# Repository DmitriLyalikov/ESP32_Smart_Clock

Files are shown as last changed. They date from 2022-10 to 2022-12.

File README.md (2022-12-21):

# ESP32 Smart Clock 
This is my Embedded Systems Design Semester Project. I am using the ESP32 platform to make a LCD digital clock that displays local time synchronised from an NTP server and local/current weather forecasts from a JSON weather API endpoint over HTTP. 

This repository contains all the subcomponents, design files, and source code for this system. It is designed to work out 'of the box'. 

Demonstration Video: https://www.youtube.com/watch?v=tQ15JdgLJVc

worker - Copy
### Demonstration Hardware 
* ESP32-DevKitC-V4 (ESP32 Based evaluation board)
* LCD 2004            ( 4x16 LCD)
* PCF8574 I2C Adaptor ( LCD I2C Controller)
* 3D Printed PLA Enclosure ( Front, Rear, and Side Supports)

#### Enclosure 
The 3D printed .stl design files are included in the /enclosure subdirectory. These three components are printed using the Creality CR-10S4 3D printer. Total printing time is about 6.5 hours with the following settings. The output file was generated using the Ultimaker Cura software.
#### Input File


* Resolution: .28
* Infill: 5%
* Material: PLA 

#### Output:
Output

#### Assembled:
Front_View

### Live Weather 
Weather information like Precipitation, Clouds, Pressure, Temperature, Wind are accessed for the desired City or GeoLocation via the  https://openweathermap.org/current HTTP server. This has an API which processes HTTP requests and returns a JSON response including the weather data. 

#### API interaction
An API key is required to acceess the API. It is also appended into the query string of HTTP requests. To get a new API key for a new device, register at https://openweathermap.org/api.  



To verify this key works correctly, wait 10 minutes since activation and request this URL in a browser:
```console
http://api.openweathermap.org/data/2.5/weather?q=Lisbon,pt&APPID={yourAPIkey}
```

The base endpoint is: 
```console 
api.openweathermap.org/data/2.5/weather
```
A query parameter is passed that includes the City, Country code following 
ISO 31666 Country codes (https://en.wikipedia.org/wiki/List_of_ISO_3166_country_codes. 
In our case for New York City, USA the q-parameter is: 
```console
q=NY,US
```

With both an API key, and city, a complete query will appear as: 
```console
http://api.openweathermap.org/data/2.5/weather?q={City},pt&APPID={yourAPIkey}
```

### NTP Synchronization
In order to synchronize time accurately, the ESP-IDF LwIP SNTP module is used. https://github.com/espressif/esp-idf/tree/master/examples/protocols/sntp
This provides time synchronizations over WiFi upon initialization. Upon reset, WiFi will be initialized and an SNTP server connection will be started with the ESP32 acting as a client. 

#### Set Timezone
To set local timezone, use setenv and tzset POSIX functions. First, call setenv to set TZ environment variable to the correct value depending on device location. Format of the time string is described in libc documentation. Next, call tzset to update C library runtime data for the new time zone. Once these steps are done, localtime function will return correct local time, taking time zone offset and daylight saving time into account.

#### TimeKeeping
Once time is synchronized, ESP32 will perform timekeeping using built-in timers.

* RTC clock is used to maintain accurate time when chip is in deep sleep mode

* High-resolution timer is used to provide time at microsecond accuracy when ESP32 is running.

### Using this application
This application is created in the esp-idf framework. The toolchain, compiler, drivers, all can be installed locally here: https://docs.espressif.com/projects/esp-idf/en/latest/esp32/get-started/

This application was developed on a Windows system, and the windows installer: https://docs.espressif.com/projects/esp-idf/en/latest/esp32/get-started/windows-setup.html can be found here that automates the setup process. 
Upon installation and following these steps, a ESP_IDF 4.x CMD utility will be installed, which is a development environment for esp-idf based projects. Open this. I used version 4.4, but a newer version may be available upon completion of this project.
#### Configure ESP-IDF
```console
install
export.bat
```
#### Configure and build this project
```console
cd projects
git clone https://github.com/DmitriLyalikov/ESP32_Smart_Clock.git
cd ESP32_Smart_Clock
idf.py fullclean
idf.py set-target ESP32
idf.py build
```

#### Flashing and Running
With the ESP32 connected via USB, connected to 'COMx'
```
idf.py flash monitor 'COMx'
```
This will flash the application onto the system, and restart, it will then provide serial access to the application. This is not needed to use the clock, but is useful to ensure it flashed successfully. 

#### Configure Application settings
Some configurations may need to be made when using this application. Wifi SSID, Password, and authentication mode must be set before using this app, or the defaults will be used. Generally each component will have a configuration manager that is defined in components/component/Kconfig.Projbuild . Instead of editing hard-coded values in each component source file, a menuconfig utility is provided that can edit these values via command utility:
```console
idf.py menuconfig
```
* Menuconfig Main menu


* Wifi Configuration 


### General Project Structure
```
├── CMakeLists.txt
├── components                 Developer created component sources
    |──ble-config              Bluetooth/BLE configuration functions for controlling system settings at runtime
    |──htttp                   Creates/Processes HTTP requests
    ├──i2c-lcd1602             Functions and resources to interact with an LCD display. 3rd party library (will not be tested)
    |──jsmn                    Third Party lightweight JSON parser: https://github.com/zserge/jsmn
    ├──esp32-smbus             smbus/i2c driver that lcd requires. 3rd party library (will not be tested)
    ├──net_ctlr                event handler, wifi config, web request functions for networking functions (May be split up into further subcomponents)
    ├──ntp_sync                NTP-RTC functions for time synchronization
    ├──weather_sync            Request/Get/Parse/Send Weather Requests over HTTP with thread safe queue implementation between tasks/timers
├── main
│   ├── CMakeLists.txt
│   ├── component.mk    
│   |── Kconfig.Projbuild
│   └── Weather_Clock.c        Entry point to main application. 
├── test                       Unity based subproject for entering test application
│   ├── CMakeLists.txt   
│   ├── component.mk    
│   |── main                     
│   └── build
├── enclosure                  Design (.stl) files for 3D printed system enclosure
├── schematic                  .pdf files of circuit schematic for prototype design. TODO: Create custom PCB 
├── Makefile                   Makefile used by legacy GNU Make
└── README.md                  This is the file you are currently reading
```

### Component Structure
Each component contains an include directory where the component_name.h is kept, and a test subdirectory where unit tests are defined for this component.
As discussed before, each component also has a KConfig.Projbuild that is used to configure some settings like pin assignments, clock rates, etc. 
```
├── CMakeLists.txt
├── component.mk
├── component_name.c
├── KConfig.Projbuild
├── include              
    ├──component_name.h                   
├── test
│   ├── CMakeLists.txt
│   ├── component.mk    
│   └── test_component_name.c  
```
This structure allows a clear dependency tree for our entry point at Weather_Clock.c in /main. All functions, definitions and types are brought into the main namespace by including the header file in our application. It is important to note that this inclusion also brings the components dependencies into scope as well. For example, i2c-lcd1602 component depends on the esp32-smbus component for its i2c driver, and by using #include "i2c-lcd1602.h" in Weather_Clock.c,
esp32-smbus has also been included, by association. 
### Testing
To verify that the system components work as designed, a /test directory is created that compiles a test binary based on the Unity framework for unit testing. Each component also has a /test subdirectory, ie. /components/net_ctlr/test that has defined Test cases with the unity macro: TEST_CASE("Test_name", "[args]")

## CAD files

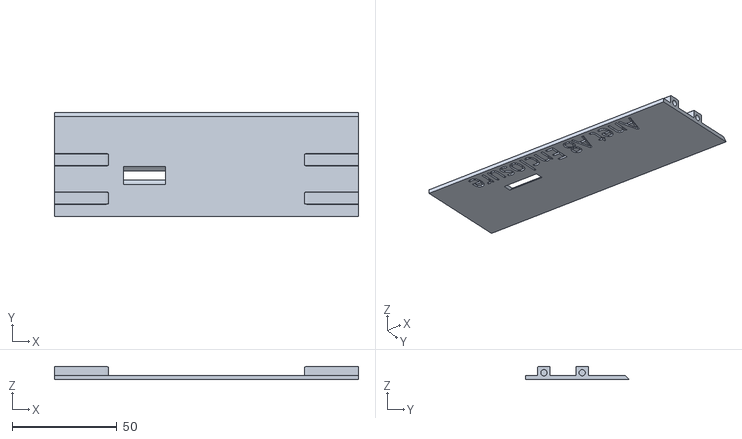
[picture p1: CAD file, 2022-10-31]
enclosure/lcd_support_rear_v3.stl
145.0 x 49.5 x 6.25

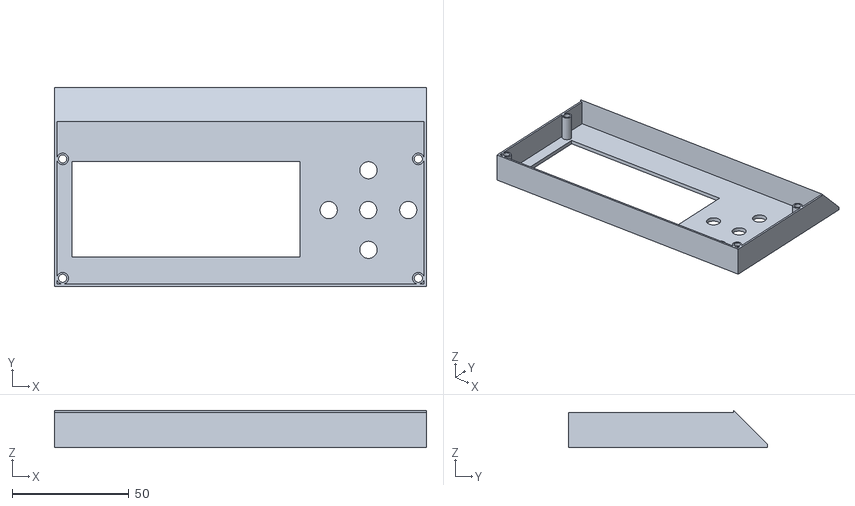
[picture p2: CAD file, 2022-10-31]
enclosure/lcd_front_v3.stl
159.0 x 85.0 x 16.0

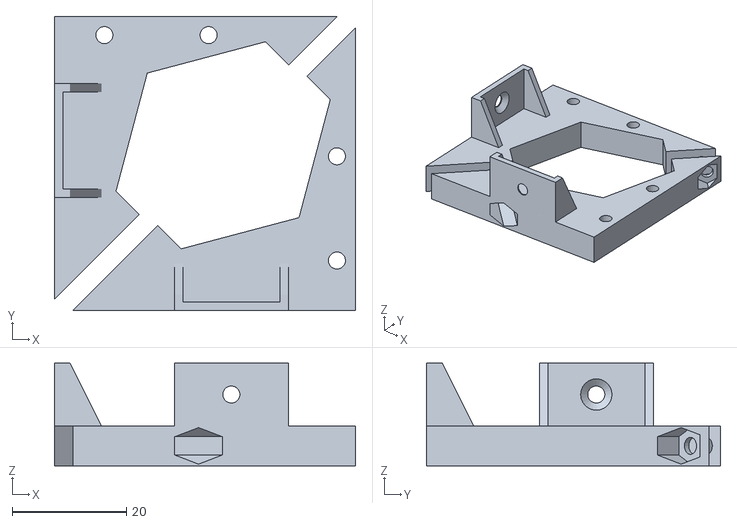
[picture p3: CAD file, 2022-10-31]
enclosure/lcd_supports_45_v3.stl
52.8 x 51.5 x 18.0

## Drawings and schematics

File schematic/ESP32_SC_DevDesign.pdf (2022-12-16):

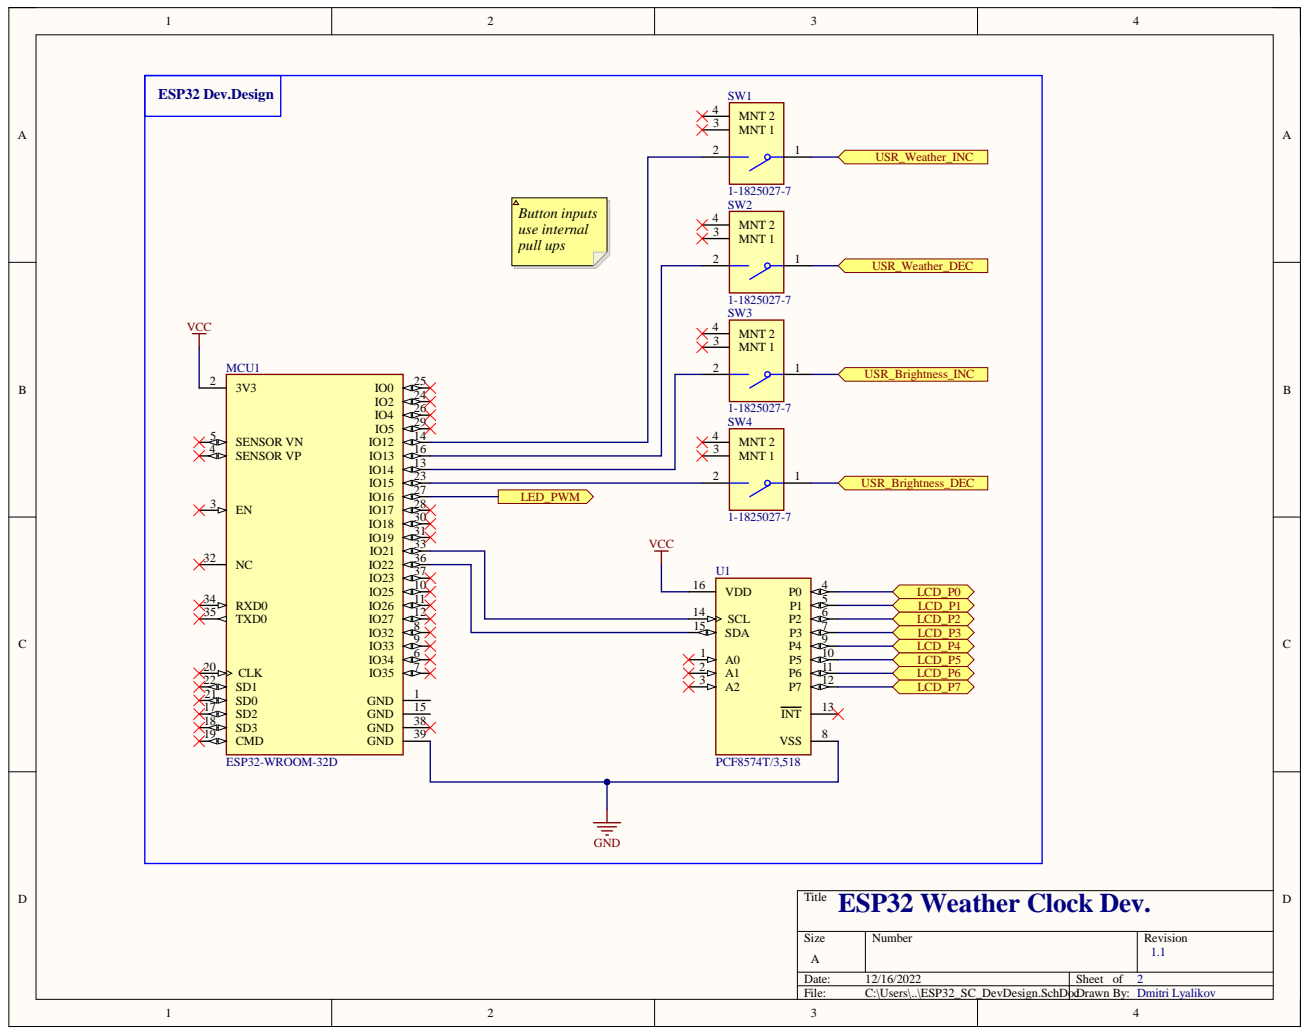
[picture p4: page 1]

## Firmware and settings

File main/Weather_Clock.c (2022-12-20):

/**
 * @file Weather_Clock.c
 * @author Dmitri Lyalikov (Dlyalikov01@manhattan.edu)
 * @brief  Entry Point to ESP32 Weather Clock Application for EECE 321 Final Project 
 * @version 1.2
 * @date 2022-11-14
 */

#include <stdio.h>
#include <string.h>
#include <time.h> 

#include <sys/time.h>
#include "esp_log.h"
#include "esp_err.h"
#include "esp_system.h"
#include "freertos/FreeRTOS.h"
#include "freertos/task.h"
#include "freertos/timers.h"
#include "nvs_flash.h"
#include "perfmon.h"
#include "sdkconfig.h"
#include "driver/i2c.h"

#include "ble_config.h"
#include "smbus.h"
#include "i2c-lcd1602.h"
#include "net_ctlr.h"
#include "ntp_sync.h"
#include "weather.h"
#include "button_irq.h"

#define TIMEZONE              CONFIG_TIMEZONE
#define CITY                  CONFIG_CITY
#define NTP_RESYNC_PERIOD     CONFIG_NTP_RESYNC_PERIOD
#define WEATHER_RESYNC_PERIOD CONFIG_NTP_RESYNC_PERIOD

static const char* TAG = "Weather Clock";

// FreeRTOS Task Shared Resources
static TimerHandle_t xNTP_SYNC_TIMER;
static TimerHandle_t xWEATHER_SYNC_TIMER;
static QueueHandle_t xWeatherSyncQueue;

/**
 * @brief Initialise I2C Master Bus before display communication
 */
static void i2c_master_init(void)
{
    int i2c_master_port = I2C_MASTER_NUM;
    i2c_config_t conf;
    memset(&conf, 0, sizeof(i2c_config_t));
    conf.mode = I2C_MODE_MASTER;
    conf.sda_io_num = I2C_MASTER_SDA_IO;
    conf.sda_pullup_en = GPIO_PULLUP_DISABLE;  // GY-2561 provides 10kΩ pullups
    conf.scl_io_num = I2C_MASTER_SCL_IO;
    conf.scl_pullup_en = GPIO_PULLUP_DISABLE;  // GY-2561 provides 10kΩ pullups
    conf.master.clk_speed = I2C_MASTER_FREQ_HZ;
    i2c_param_config(i2c_master_port, &conf);
    i2c_driver_install(i2c_master_port, conf.mode,
                       I2C_MASTER_RX_BUF_LEN,
                       I2C_MASTER_TX_BUF_LEN, 0);
}

/**
 * @brief Display Task 
 * Configure I2C, SMbus, and LCD device
 * Set time zone, get weather data
 * Updates time every 500 ms, and writes to Display
 */
static void vdisplay_task(void *pvParameter) {
    i2c_master_init();
    i2c_port_t i2c_num = I2C_MASTER_NUM;
    uint8_t address = LCD1602_I2C_ADDRESS;

    // Set up the SMBus
    smbus_info_t * smbus_info = smbus_malloc();
    ESP_ERROR_CHECK(smbus_init(smbus_info, i2c_num, address));
    ESP_ERROR_CHECK(smbus_set_timeout(smbus_info, 1000 / portTICK_RATE_MS));

    // Set up the LCD1602 device with backlight off
    i2c_lcd1602_info_t * lcd_info = i2c_lcd1602_malloc();
    ESP_ERROR_CHECK(i2c_lcd1602_init(lcd_info, smbus_info, true,
                    LCD_NUM_ROWS, LCD_NUM_COLUMNS, LCD_NUM_VISIBLE_COLUMNS));

    ESP_ERROR_CHECK(i2c_lcd1602_reset(lcd_info));

    i2c_lcd1602_write_string(lcd_info, "    Hello Dmitri");
    i2c_lcd1602_move_cursor(lcd_info, 0, 1);
    i2c_lcd1602_write_string(lcd_info, CONFIG_CITY);
     
    weather_data weather_now;
    uint32_t ulWeatherReady;
    vReadQueue(&weather_now, xWeatherSyncQueue);
    char float_read[50];
    time_t now;
    char strftime_buf[64];
    struct tm timeinfo;
    // Set timezone to CONFIG_TIMEZONE
    time(&now);
    setenv("TZ", TIMEZONE, 1);
    tzset();
    i2c_lcd1602_move_cursor(lcd_info, 0, 1);
    i2c_lcd1602_write_string(lcd_info, CONFIG_CITY);
    i2c_lcd1602_move_cursor(lcd_info, sizeof(CONFIG_CITY), 1);
    i2c_lcd1602_write_string(lcd_info, weather_now.description);
    i2c_lcd1602_move_cursor(lcd_info, 0, 3);
    i2c_lcd1602_write_string(lcd_info, "Temp(C):");
    i2c_lcd1602_move_cursor(lcd_info, 8, 3);
    sprintf(float_read, "%d", (int)weather_now.temperature);
    i2c_lcd1602_write_string(lcd_info, float_read);
    i2c_lcd1602_write_char(lcd_info, I2C_LCD1602_CHARACTER_DEGREE);
    for (;;)
    {
      // Get Current Time from RTC 
      now = time(NULL);
      // Non-Blocking check if new Weather data is ready 
      ulWeatherReady = ulTaskNotifyTake(pdTRUE, 0);
      if (ulWeatherReady) {
          vReadQueue(&weather_now, xWeatherSyncQueue);
          i2c_lcd1602_move_cursor(lcd_info, sizeof(CONFIG_CITY), 1);
          i2c_lcd1602_write_string(lcd_info, weather_now.description);
          i2c_lcd1602_move_cursor(lcd_info, 0, 3);
          i2c_lcd1602_write_string(lcd_info, "Temp(C):");
          i2c_lcd1602_move_cursor(lcd_info, 8, 3);
          sprintf(float_read, "%d", (int)weather_now.temperature);
          i2c_lcd1602_write_string(lcd_info, float_read);
          i2c_lcd1602_write_char(lcd_info, I2C_LCD1602_CHARACTER_DEGREE);
      }

      localtime_r(&now, &timeinfo);
      strftime(strftime_buf, sizeof(strftime_buf), "%c", &timeinfo);

      i2c_lcd1602_move_cursor(lcd_info, 0, 2);
      i2c_lcd1602_write_string(lcd_info, strftime_buf);
      ESP_LOGI(TAG, "Got current date/time in %s: %s", CITY, strftime_buf);   
      i2c_lcd1602_move_cursor(lcd_info, 0, 1);
      i2c_lcd1602_write_string(lcd_info, CONFIG_CITY);
      vTaskDelay(100 / portTICK_PERIOD_MS);
    }
}

/**
 * @brief NTP Synchronization Timer Callback
 *     Must be used after WiFI connection is established.
 *     Syncs RTC clock time with ntp server
 * @param xTimerHandle
 */
void vTimeSync_Callback(TimerHandle_t xTimer) {
  ESP_LOGI(TAG, "Re-Synchronizing RTC time from NTP Server\n");
  ntp_wait_for_sync();
}

/**
 * @brief Thread-Safe Weather Synchronization Timer Callback
 *      Must be used after WiFi connection is established.
 *      Sends Weather request to weather server api and processes JSON response
 *      write Weather_Payload_t to xWeatherQueue mailbox 
 * @param xTimerHandle 
 */
void vWeatherSync_Callback(TimerHandle_t xTimer) {
  ESP_LOGI(TAG, "Starting Weather Request...");
  http_weather_request(xWeatherSyncQueue);
  xTaskNotifyGive(vdisplay_task);
}

/**
 * @brief Entry Point to Application
 *      Display task is very active and resource needy, so it is put on Core 1
 *      Software timers: xNTP_SYNC_TIMER and WEATHER_SYNC_TIMER are on Core 0,
 *      they do not fire often and can generally be neglected
 *      Networking functionality is kept on core 0
 */
void app_main(void)
{
    //Initialize NVS
    esp_err_t ret = nvs_flash_init();
    if (ret == ESP_ERR_NVS_NO_FREE_PAGES || ret == ESP_ERR_NVS_NEW_VERSION_FOUND) {
      ESP_ERROR_CHECK(nvs_flash_erase());
      ret = nvs_flash_init();
    }
    ESP_ERROR_CHECK(ret);

    timezone_set(TIMEZONE);
    ESP_LOGI(TAG, "********ESP32 Weather Clock Application********");
    // Initialise WiFI station
    wifi_init_sta();
    // Start RTC sync with NTP 
    ntp_start();
    ntp_wait_for_sync();
  
    xNTP_SYNC_TIMER = xTimerCreate("NTP Resync Timer",
                                  (NTP_RESYNC_PERIOD * 1000) / portTICK_PERIOD_MS,
                                  pdTRUE,
                                  ( void * ) 0,
                                  vTimeSync_Callback);
    if( xTimerStart(xNTP_SYNC_TIMER, 0 ) != pdPASS ) {
      ESP_LOGI(TAG, "Could not start xNTP_SYNC_TIMER");
    }

    xWeatherSyncQueue = vQueueInit();
    ESP_LOGI(TAG, "Starting Weather Request...");
    initialise_weather_data_retrieval(WEATHER_RESYNC_PERIOD);
    http_weather_request(xWeatherSyncQueue);
    xWEATHER_SYNC_TIMER = xTimerCreate("Weather Resync Timer",
                                      (WEATHER_RESYNC_PERIOD * 1000) / portTICK_PERIOD_MS,
                                      pdTRUE,
                                      (void * ) 0,
                                      vWeatherSync_Callback);
    if( xTimerStart(xWEATHER_SYNC_TIMER, 0 ) != pdPASS ) {
      ESP_LOGI(TAG, "Could not start xWEATHER_SYNC_TIMER");
    }
    // Start display task on Core 1
    xTaskCreatePinnedToCore(&vdisplay_task,
                            "xTask_Display",
                            2048,
                            NULL,
                            1, 
                            NULL,
                            1);
    // Register brightness button ISRs and start LCD brightness background task
    vPWM_Control_Init();
}

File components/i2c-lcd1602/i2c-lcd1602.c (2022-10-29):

/**
 * @file
 *
 * @brief
 * The LCD1602 controller is an HD44780-compatible controller that normally operates
 * via an 8-bit or 4-bit wide parallel bus.
 *
 * The LCD1602 controller is connected to a PCF8574A I/O expander via the I2C bus.
 * Only the top four bits are connected to the controller's data lines. The lower
 * four bits are used as control lines:
 *
 *   - B7: data bit 3
 *   - B6: data bit 2
 *   - B5: data bit 1
 *   - B4: data bit 0
 *   - B3: backlight (BL): off = 0, on = 1
 *   - B2: enable (EN): change from 1 to 0 to clock data into controller
 *   - B1: read/write (RW): write = 0, read = 1
 *   - B0: register select (RS): command = 0, data = 1
 *
 * Therefore to send a command byte requires the following operations:
 *
 *   // First nibble:
 *   val = command & 0xf0              // extract top nibble
 *   val |= 0x04                       // RS = 0 (command), RW = 0 (write), EN = 1
 *   i2c_write_byte(i2c_address, val)
 *   sleep(2ms)
 *   val &= 0xfb                       // EN = 0
 *   i2c_write_byte(i2c_address, val)
 *
 *   // Second nibble:
 *   val = command & 0x0f              // extract bottom nibble
 *   val |= 0x04                       // RS = 0 (command), RW = 0 (write), EN = 1
 *   i2c_write_byte(i2c_address, val)
 *   sleep(2ms)
 *   val &= 0xfb                       // EN = 0
 *   i2c_write_byte(i2c_address, val)
 *
 * Sending a data byte is very similar except that RS = 1 (data)
 *
 * When the controller powers up, it defaults to:
 *
 *   - display cleared
 *   - 8-bit interface, 1 line display, 5x8 dots per character
 *   - increment by 1 set
 *   - no shift
 *
 * The controller must be set to 4-bit operation before proper communication can commence.
 * The initialisation sequence for 4-bit operation is:
 *
 *   0. wait > 15ms after Vcc rises to 4.5V, or > 40ms after Vcc rises to 2.7V
 *   1. send nibble 0x03     // select 8-bit interface
 *   2. wait > 4.1ms
 *   3. send nibble 0x03     // select 8-bit interface again
 *   4. wait > 100us
 *   5. send command 0x32    // select 4-bit interface
 *   6. send command 0x28    // set 2 lines and 5x7(8?) dots per character
 *   7. send command 0x0c    // display on, cursor off
 *   8. send command 0x06    // move cursor right when writing, no scroll
 *   9. send command 0x80    // set cursor to home position (row 1, column 1)
 */

#include <stddef.h>
#include <string.h>

#include "freertos/FreeRTOS.h"
#include "freertos/task.h"
#include "esp_system.h"
#include "esp_log.h"

#include "i2c-lcd1602.h"

#define TAG "i2c-lcd1602"

// Delays (microseconds)
#define DELAY_POWER_ON            50000  // wait at least 40us after VCC rises to 2.7V
#define DELAY_INIT_1               4500  // wait at least 4.1ms (fig 24, page 46)
#define DELAY_INIT_2               4500  // wait at least 4.1ms (fig 24, page 46)
#define DELAY_INIT_3                120  // wait at least 100us (fig 24, page 46)

#define DELAY_CLEAR_DISPLAY        2000
#define DELAY_RETURN_HOME          2000

#define DELAY_ENABLE_PULSE_WIDTH      1  // enable pulse must be at least 450ns wide
#define DELAY_ENABLE_PULSE_SETTLE    50  // command requires > 37us to settle (table 6 in datasheet)


// Commands
#define COMMAND_CLEAR_DISPLAY       0x01
#define COMMAND_RETURN_HOME         0x02
#define COMMAND_ENTRY_MODE_SET      0x04
#define COMMAND_DISPLAY_CONTROL     0x08
#define COMMAND_SHIFT               0x10
#define COMMAND_FUNCTION_SET        0x20
#define COMMAND_SET_CGRAM_ADDR      0x40
#define COMMAND_SET_DDRAM_ADDR      0x80

// COMMAND_ENTRY_MODE_SET flags
#define FLAG_ENTRY_MODE_SET_ENTRY_INCREMENT       0x02
#define FLAG_ENTRY_MODE_SET_ENTRY_DECREMENT       0x00
#define FLAG_ENTRY_MODE_SET_ENTRY_SHIFT_ON        0x01
#define FLAG_ENTRY_MODE_SET_ENTRY_SHIFT_OFF       0x00

// COMMAND_DISPLAY_CONTROL flags
#define FLAG_DISPLAY_CONTROL_DISPLAY_ON  0x04
#define FLAG_DISPLAY_CONTROL_DISPLAY_OFF 0x00
#define FLAG_DISPLAY_CONTROL_CURSOR_ON   0x02
#define FLAG_DISPLAY_CONTROL_CURSOR_OFF  0x00
#define FLAG_DISPLAY_CONTROL_BLINK_ON    0x01
#define FLAG_DISPLAY_CONTROL_BLINK_OFF   0x00

// COMMAND_SHIFT flags
#define FLAG_SHIFT_MOVE_DISPLAY          0x08
#define FLAG_SHIFT_MOVE_CURSOR           0x00
#define FLAG_SHIFT_MOVE_LEFT             0x04
#define FLAG_SHIFT_MOVE_RIGHT            0x00

// COMMAND_FUNCTION_SET flags
#define FLAG_FUNCTION_SET_MODE_8BIT      0x10
#define FLAG_FUNCTION_SET_MODE_4BIT      0x00
#define FLAG_FUNCTION_SET_LINES_2        0x08
#define FLAG_FUNCTION_SET_LINES_1        0x00
#define FLAG_FUNCTION_SET_DOTS_5X10      0x04
#define FLAG_FUNCTION_SET_DOTS_5X8       0x00

// Control flags
#define FLAG_BACKLIGHT_ON    0b00001000      // backlight enabled (disabled if clear)
#define FLAG_BACKLIGHT_OFF   0b00000000      // backlight disabled
#define FLAG_ENABLE          0b00000100
#define FLAG_READ            0b00000010      // read (write if clear)
#define FLAG_WRITE           0b00000000      // write
#define FLAG_RS_DATA         0b00000001      // data (command if clear)
#define FLAG_RS_COMMAND      0b00000000      // command

static bool _is_init(const i2c_lcd1602_info_t * i2c_lcd1602_info)
{
    bool ok = false;
    if (i2c_lcd1602_info != NULL)
    {
        if (i2c_lcd1602_info->init)
        {
            ok = true;
        }
        else
        {
            ESP_LOGE(TAG, "i2c_lcd1602_info is not initialised");
        }
    }
    else
    {
        ESP_LOGE(TAG, "i2c_lcd1602_info is NULL");
    }
    return ok;
}

 // Set or clear the specified flag depending on condition
 static uint8_t _set_or_clear(uint8_t flags, bool condition, uint8_t flag)
 {
     if (condition)
     {
         flags |= flag;
     }
     else
     {
         flags &= ~flag;
     }
     return flags;
 }

// send data to the I/O Expander
static esp_err_t _write_to_expander(const i2c_lcd1602_info_t * i2c_lcd1602_info, uint8_t data)
{
    // backlight flag must be included with every write to maintain backlight state
    ESP_LOGD(TAG, "_write_to_expander 0x%02x", data | i2c_lcd1602_info->backlight_flag);
    return smbus_send_byte(i2c_lcd1602_info->smbus_info, data | i2c_lcd1602_info->backlight_flag);
}

// IMPORTANT - for the display to stay "in sync" it is important that errors do not interrupt the
// 2 x nibble sequence.

// clock data from expander to LCD by causing a falling edge on Enable
static esp_err_t _strobe_enable(const i2c_lcd1602_info_t * i2c_lcd1602_info, uint8_t data)
{
    esp_err_t err1 = _write_to_expander(i2c_lcd1602_info, data | FLAG_ENABLE);
    ets_delay_us(DELAY_ENABLE_PULSE_WIDTH);
    esp_err_t err2 = _write_to_expander(i2c_lcd1602_info, data & ~FLAG_ENABLE);
    ets_delay_us(DELAY_ENABLE_PULSE_SETTLE);
    return err1 ? err1 : err2;
}
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

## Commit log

2022-10-28 create unity rest framework
2022-10-28 test framework working
2022-10-29 created i2c lcd display components
    verified test and main compilation
    added esp32-smbus, renamed display-driver component to i2c-lcd1602.
2022-10-29 created i2c_master_init/vdisplay_task
    Not sure what display task will do repeatedly.
    need to understand unit of queue payload. how does NTP work with synchronizing. seems like NTP done once and queue only used for weather data.
2022-10-31 Use ESP_ LOGI instead of print
2022-10-31 Restructure to contain design files for enclosure
2022-10-31 restructure to include design files for enclosure
2022-10-31 Added enclosure design
    [lcd_front_NO_TEXT.stl, lcd_support_completemodel.stl, lcd_support_completemodel_v3.stl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]
2022-10-31 created 3d files
    [lcd_front_v3.stl, lcd_support_completemodel.stl, lcd_support_completemodel_v3.stl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]
2022-10-31 added .stl files in enclosure subdir
    [lcd_front_v3.stl, lcd_support_rear_v3.stl, lcd_supports_45_v3.stl]
2022-10-31 added enclosure subdirectory
2022-10-31 changed LCD interface
    seems that i2c interface is identical, driver will remain as lcd1602 so both will be compatible. Test and confirm
2022-10-31 enclosure description
2022-11-01 added printed enclousre photos
2022-11-01 added enclosure photos
2022-11-11 added RTC timeset/get
    in Display task, get time from RTC and print date/time in City/Timezone to log.
    make sure to initialize and verify ntp sync before using this. also create timer that periodically resyncs.
2022-11-12 i2c_lcd1602 development steady build
    E (486) smbus: I2C no slave ACK
    E (486) i2c-lcd1602: reset: _write_to_expander 1 failed: -1
    not functional display task. lcd_display_init function not working for 2004 but works for 1602. will test different 1602 library on dev branch
    [Weather_Clock.c, i2c-lcd1602.c, i2c-lcd1602.h]
2022-11-12 I2C/LCD Display working/stable version
    Tested init and input functions. Working Ok. removed Kconfig
2022-11-12 added ntp_sync component and test framework
2022-11-13 added/tested NTP_RESYNC timer
2022-11-13 added weather_sync callback for timer
2022-11-14 working weather api, description, temperatue
2022-11-14 added semaphore around WeatherQueue
    -Test that blocking periods are performant
    -That current weahter is not overwritten
    -lowered display task delay to 900 to give time fo rupdates
2022-11-15 Removed semaphores around queue read/writes
    instead used xtTaskNotifyTake/Give
    for nonblocking task/timer callbacks for display to not block when weather data not ready. Thread safe. test
2022-11-15 vDisplayTask optmized speed up(40%)
    The bottleneck of the task is the amount of i2c display writes. Some did not need to be done every iteration. Removed those, found a potential bug where time overwrites second row.
    Another potential speedup is to increase i2c bus frequency.
    vdisplay_task now fires 6-7 times in a second.
    [Weather_Clock.c]
2022-12-16 added schematic
2022-12-16 added button_irq component
    defines button IRQ functions and init function to register them at runtime
2022-12-16 ISR defines for button_irq
2022-12-16 defined and built pwm control init and task functions
2022-12-16 runtime issue with allocating interrupt:
    E (39657) gpio: esp_intr_alloc failed (0x105)
    [Weather_Clock.c, button_irq.c]
2022-12-20 added separate gpio ISRs
    using gpio_isr_handler_add functions to register specific ISRs to each pwm button
